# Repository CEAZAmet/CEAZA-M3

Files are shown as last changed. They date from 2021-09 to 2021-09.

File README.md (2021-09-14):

# Welcome to CEAZA-M3!
Solar charger for 12V SLA battery in CEAZA MEGA system.
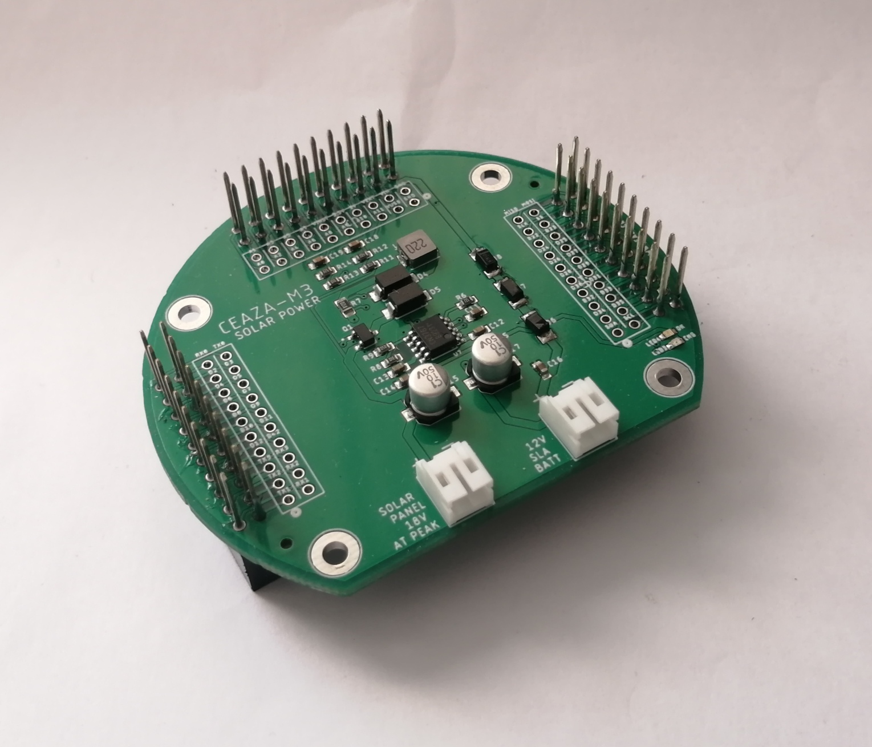
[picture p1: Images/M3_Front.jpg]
CEAZA M3 Board


# What is the CEAZA-M3?
Is a solar PWM charger for 12V SLA battery board compatible with CEAZA MEGA system, which allow recharge the system battery every day and avoid system failure due lack of energy storage.
The CEAZA M3 have below specs:
- Only for 12V SLA batteries.
- 18Vmpp Solar pannel (absolute maximum 28V)
- Solar pannel voltage monitor.
- Battery voltage monitor.
- Status LED red and green powered from solar panel which indicates charging or done respectively.
- Ready to solder pins for easy prototyping.

This board is pin compatible and should be connected to the CEAZA MEGA system to proper work.

## Documentation
A comprehensive documentation for well undertand, use or modify the CEAZA M3 board is available in our Wiki. In adition, we share with you the schematics diagrams, adns Arduino example codes.

## Quickstart guide
Install the M3 board in the CEAZA MEGA's bottom, make certain connection throuhg the boards by three 2 x 10 pin header terminals is rigth. Plug the battery and solar panel cables in the respective board terminal. be careful to avoid swap both plugs, due they are the same type of terminals. Connect the CEAZA MEGA main board system to the host PC by mini-USB connector, open the Arduino ide software, select the Arduino Mega board and the correspondign COM port.
Open any of examples scketches and upload to the board.
### WARNING!
Do not connect the battery in the main CEAZA MEGA power plug when you connect the M3 board. This may cause an electric problem in the system.

# Contact and support
For all kinds of inquiries, please contact me to my e-mail address: adrian.gallardo@ceaza.cl

# Contributing
You are welcome to contribute to the development or improvement of M3 hardware design or example application codes. Feel free to submit a new pull request via github.

# Academic Context

# Licensing

# Disclaimer
Use M3 board and examples code at your own risk. We do not encourage any malicious use of our board.

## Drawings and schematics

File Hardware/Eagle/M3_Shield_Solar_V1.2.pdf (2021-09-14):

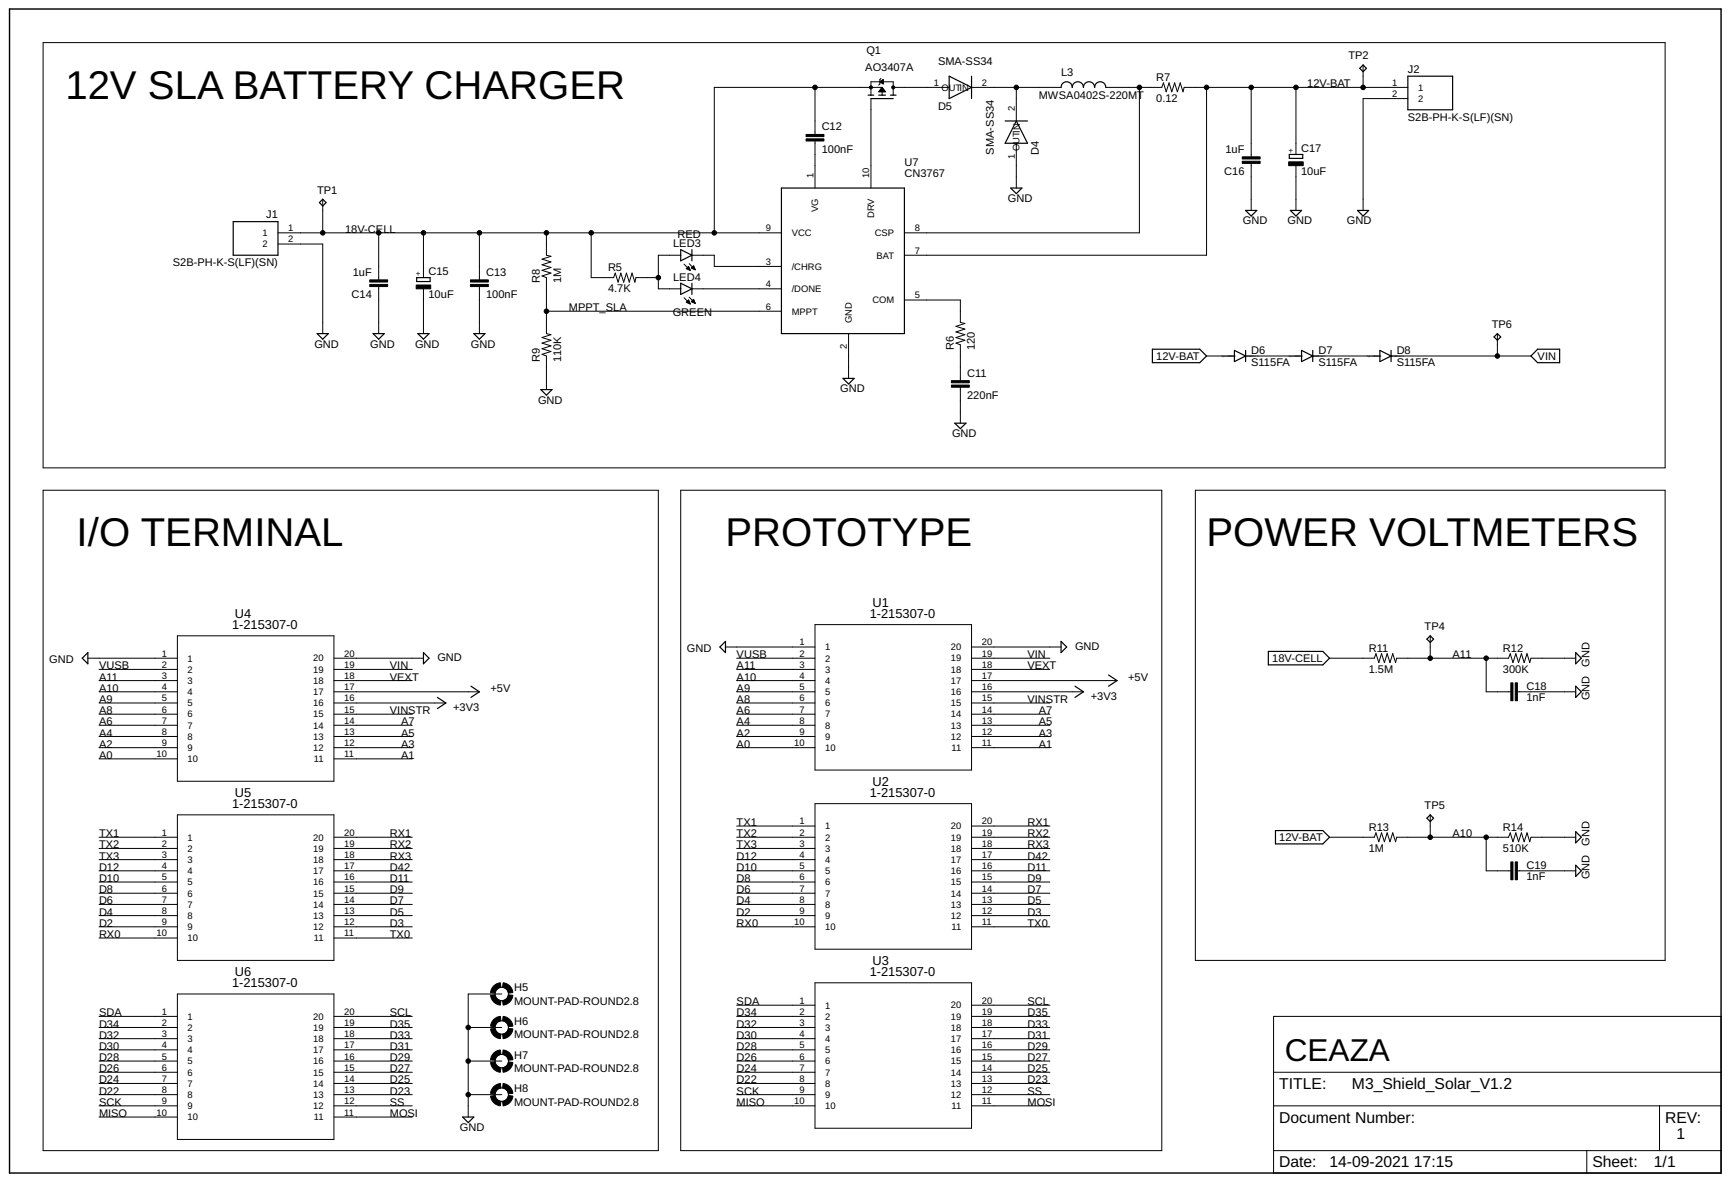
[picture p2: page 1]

+ Date: Sheet: REV: TITLE: Document Number: 14-09-2021 17:15 1/1
10uF GND

MOUNT-PAD-ROUND2.8 MOUNT-PAD-ROUND2.8 MOUNT-PAD-ROUND2.8 MOUNT-PAD-ROUND2.8 GND

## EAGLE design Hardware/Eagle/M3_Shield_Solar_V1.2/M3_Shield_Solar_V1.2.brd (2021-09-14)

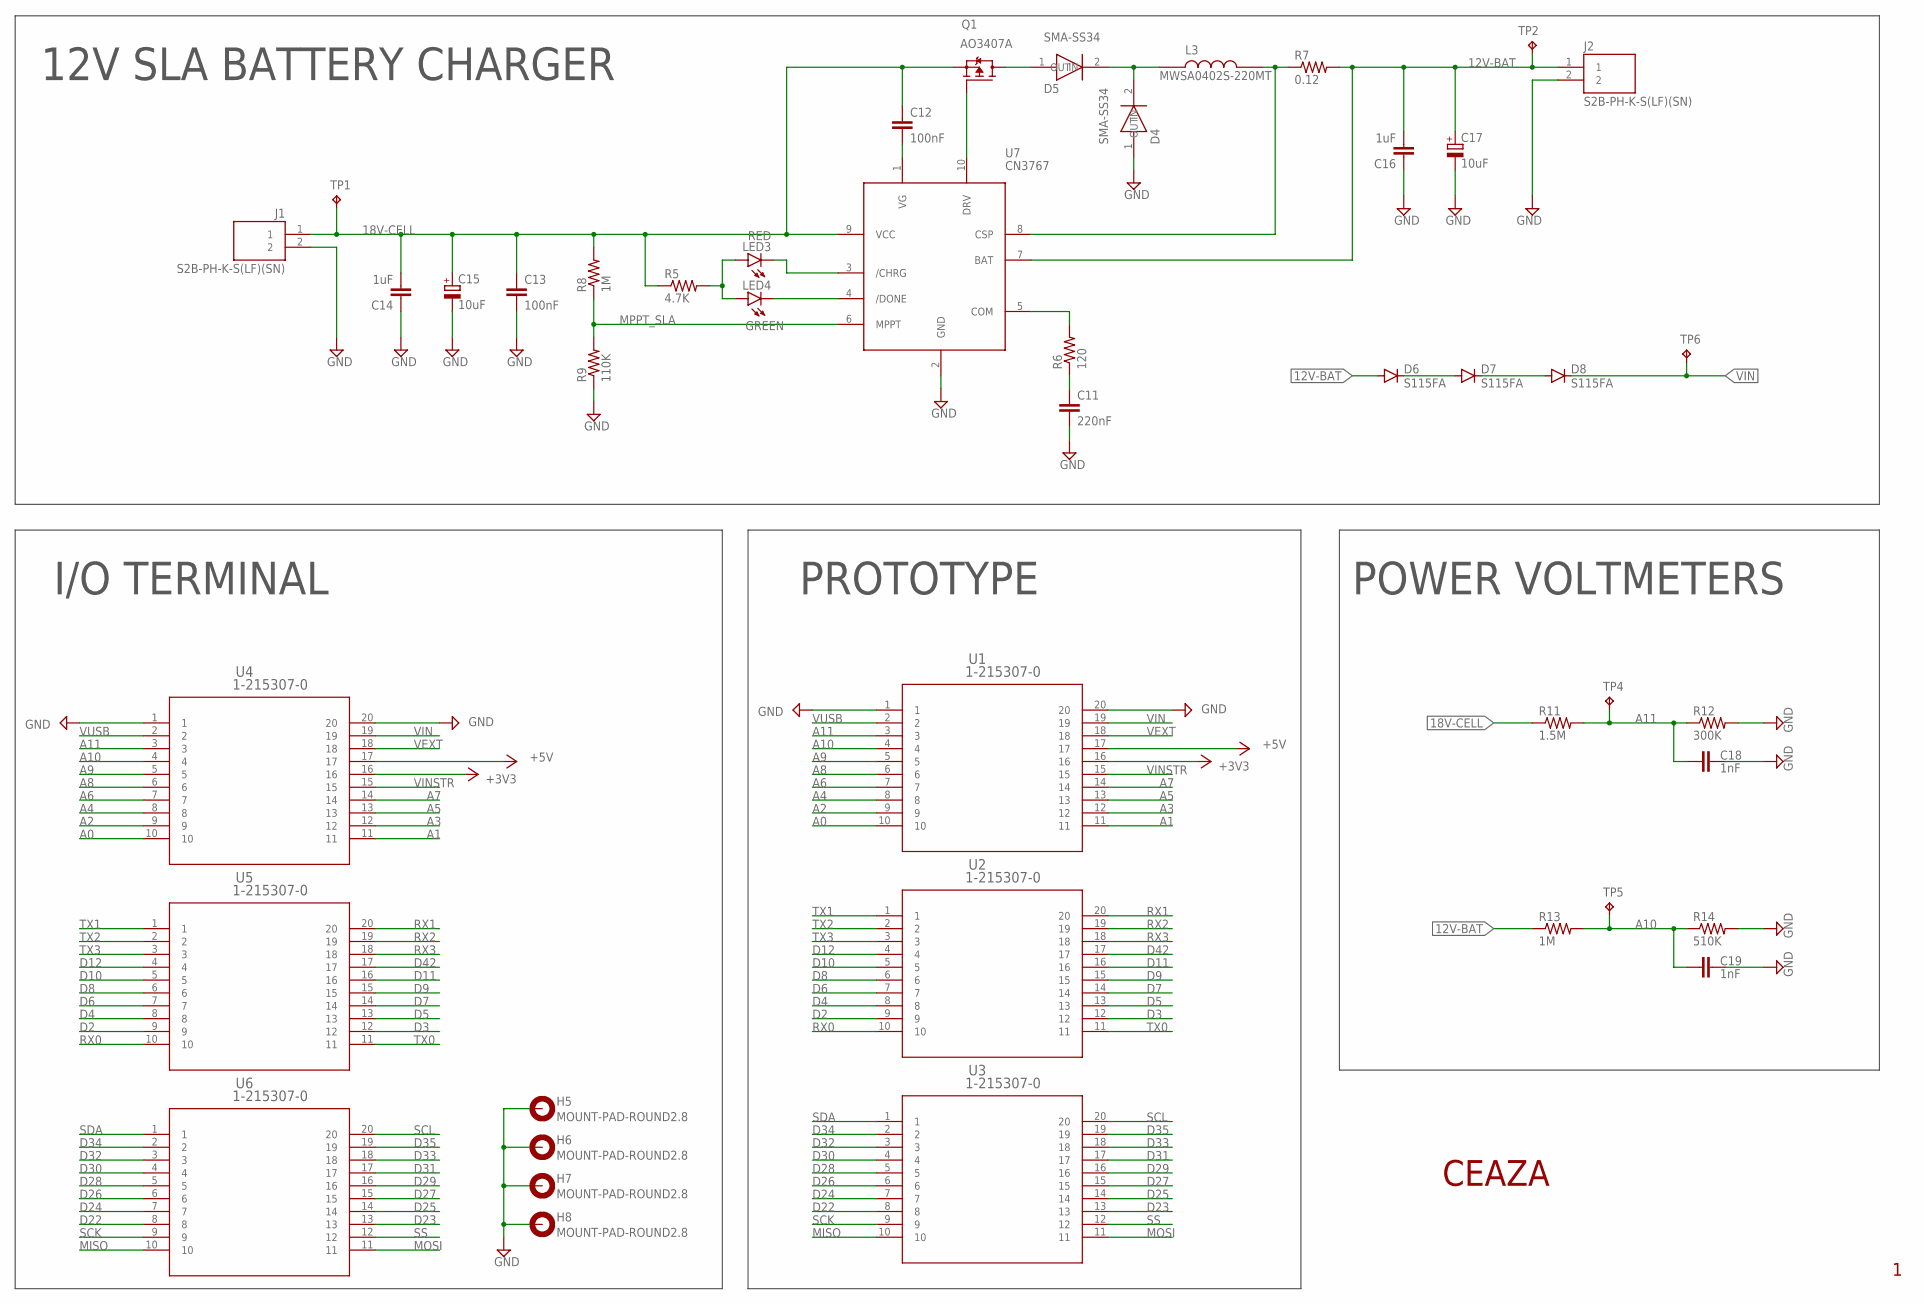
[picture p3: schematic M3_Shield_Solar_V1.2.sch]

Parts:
C11: 220nF; C0603K
C12, C13: 100nF; C0603K
C14, C16: 1uF; C0603K
C15, C17: 10uF; 153CLV-0505
C18, C19: 1nF; C0603K
D4, D5: SMA-SS34
D6, D7, D8: S115FA; SOD-123_MINI-SMA
H5, H6, H7, H8: MOUNT-PAD-ROUND2.8; 2,8-PAD
J1, J2: S2B-PH-K-S(LF)(SN); JST_S2B-PH-K-S(LF)(SN)
L3: MWSA0402S-220MT
LED3: RED; CHIPLED_0603
LED4: GREEN; CHIPLED_0603
Q1: AO3407A; SOT95P280X125-3N
R5: 4.7K; R0603
R6: 120; R0603
R7: 0.12; R0805
R8, R13: 1M; R0603
R9: 110K; R0603
R11: 1.5M; R0603
R12: 300K; R0603
R14: 510K; R0603
TP1, TP2, TP4, TP5, TP6: TPB1,27; B1,27
U1, U2, U3, U4, U5, U6: 1-215307-0
U7: CN3767

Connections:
12V-BAT: C16.2, C17.+, D6.A, J2.1, R7.2, R13.1, TP2.TP, U7.7 (BAT)
18V-CELL: C12.1, C13.1, C14.2, C15.+, J1.1, Q1.2 (S), R5.1, R8.2, R11.1, TP1.TP, U7.9 (VCC)
+3V3: U1.16, U4.16
+5V: U1.17, U4.17
A0: U1.10, U4.10
A1: U1.11, U4.11
A2: U1.9, U4.9
A3: U1.12, U4.12
A4: U1.8, U4.8
A5: U1.13, U4.13
A6: U1.7, U4.7
A7: U1.14, U4.14
A8: U1.6, U4.6
A9: U1.5, U4.5
A10: C19.1, R13.2, R14.1, TP5.TP, U1.4, U4.4
A11: C18.1, R11.2, R12.1, TP4.TP, U1.3, U4.3
D2: U2.9, U5.9
D3: U2.12, U5.12
D4: U2.8, U5.8
D5: U2.13, U5.13
D6: U2.7, U5.7
D7: U2.14, U5.14
D8: U2.6, U5.6
D9: U2.15, U5.15
D10: U2.5, U5.5
D11: U2.16, U5.16
D12: U2.4, U5.4
D22: U3.8, U6.8
D23: U3.13, U6.13
D24: U3.7, U6.7
D25: U3.14, U6.14
D26: U3.6, U6.6
D27: U3.15, U6.15
D28: U3.5, U6.5
D29: U3.16, U6.16
D30: U3.4, U6.4
D31: U3.17, U6.17
D32: U3.3, U6.3
D33: U3.18, U6.18
D34: U3.2, U6.2
D35: U3.19, U6.19
D42: U2.17, U5.17
GND: C11.2, C13.2, C14.1, C15.-, C16.1, C17.-, C18.2, C19.2, D4.1 (IN), H5.B2,8, H6.B2,8, H7.B2,8, H8.B2,8, J1.2, J2.2, R9.1, R12.2, R14.2, U1.1, U1.20, U4.1, U4.20, U7.2 (GND)
MISO: U3.10, U6.10
MOSI: U3.11, U6.11
MPPT_SLA: R8.1, R9.2, U7.6 (MPPT)
unnamed: LED4.C, U7.4 (/DONE)
unnamed: LED3.C, U7.3 (/CHRG)
unnamed: LED3.A, LED4.A, R5.2
unnamed: R6.2, U7.5 (COM)
unnamed: C11.1, R6.1
unnamed: D6.C, D7.A
unnamed: D7.C, D8.A
unnamed: L3.P$2, R7.1, U7.8 (CSP)
unnamed: D4.2 (OUT), D5.2 (OUT), L3.P$1
unnamed: C12.2, U7.1 (VG)
unnamed: Q1.1 (G), U7.10 (DRV)
unnamed: D5.1 (IN), Q1.3 (D)
RX0: U2.10, U5.10
RX1: U2.20, U5.20
RX2: U2.19, U5.19
RX3: U2.18, U5.18
SCK: U3.9, U6.9
SCL: U3.20, U6.20
SDA: U3.1, U6.1
SS: U3.12, U6.12
TX0: U2.11, U5.11
TX1: U2.1, U5.1
TX2: U2.2, U5.2
TX3: U2.3, U5.3
VEXT: U1.18, U4.18
VIN: D8.C, TP6.TP, U1.19, U4.19
VINSTR: U1.15, U4.15
VUSB: U1.2, U4.2

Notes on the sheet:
12V SLA BATTERY CHARGER
POWER VOLTMETERS
I/O TERMINAL
PROTOTYPE
CEAZA

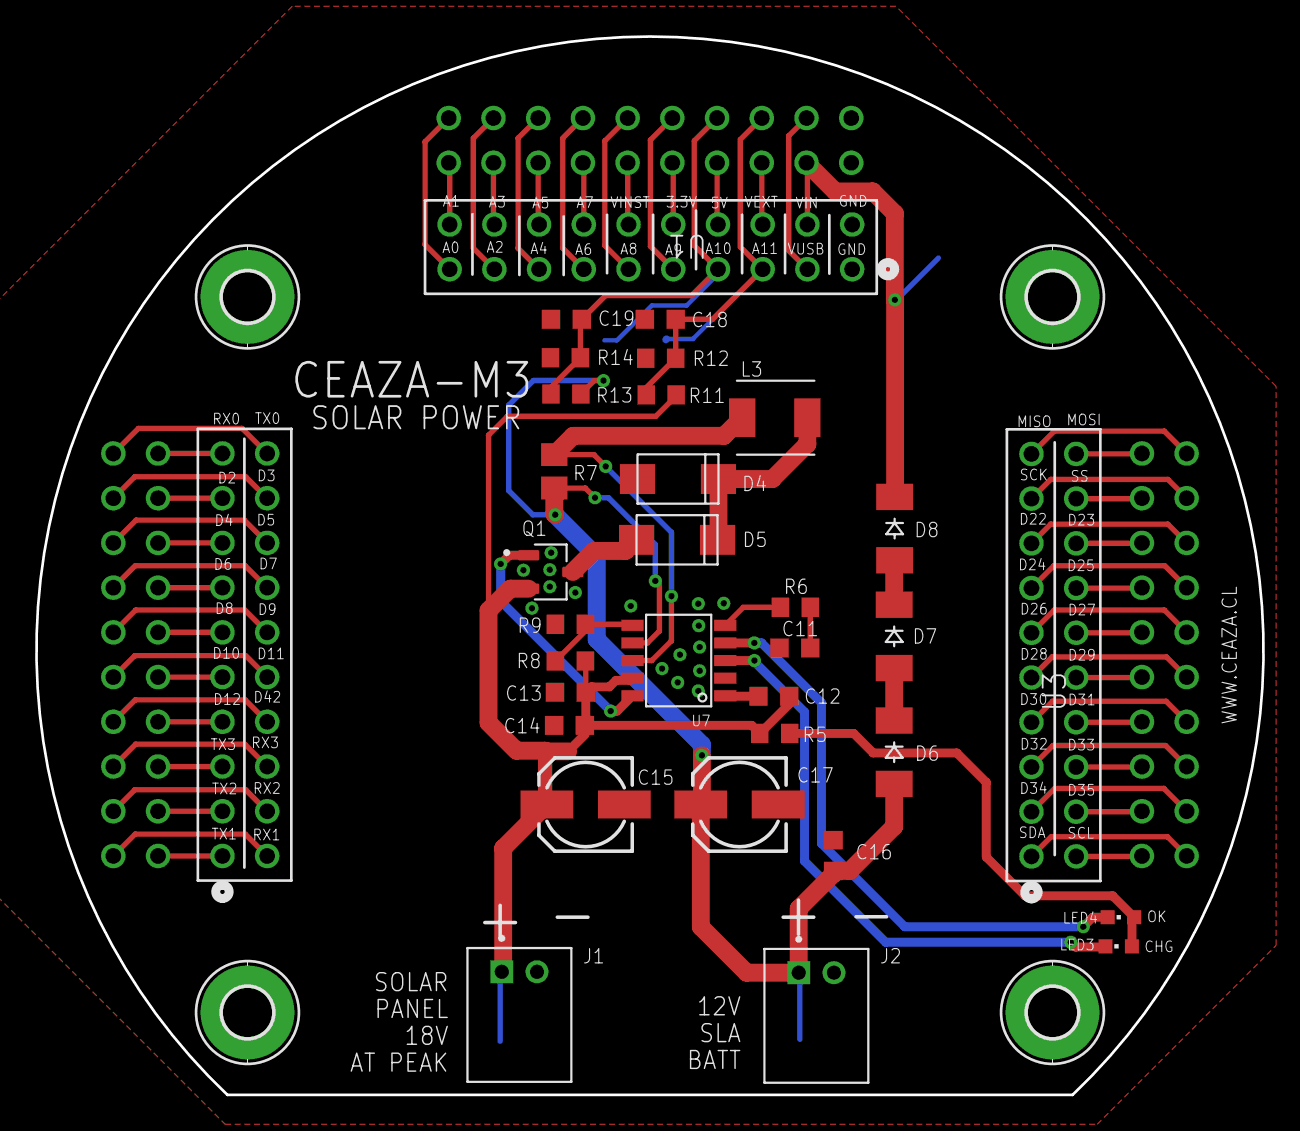
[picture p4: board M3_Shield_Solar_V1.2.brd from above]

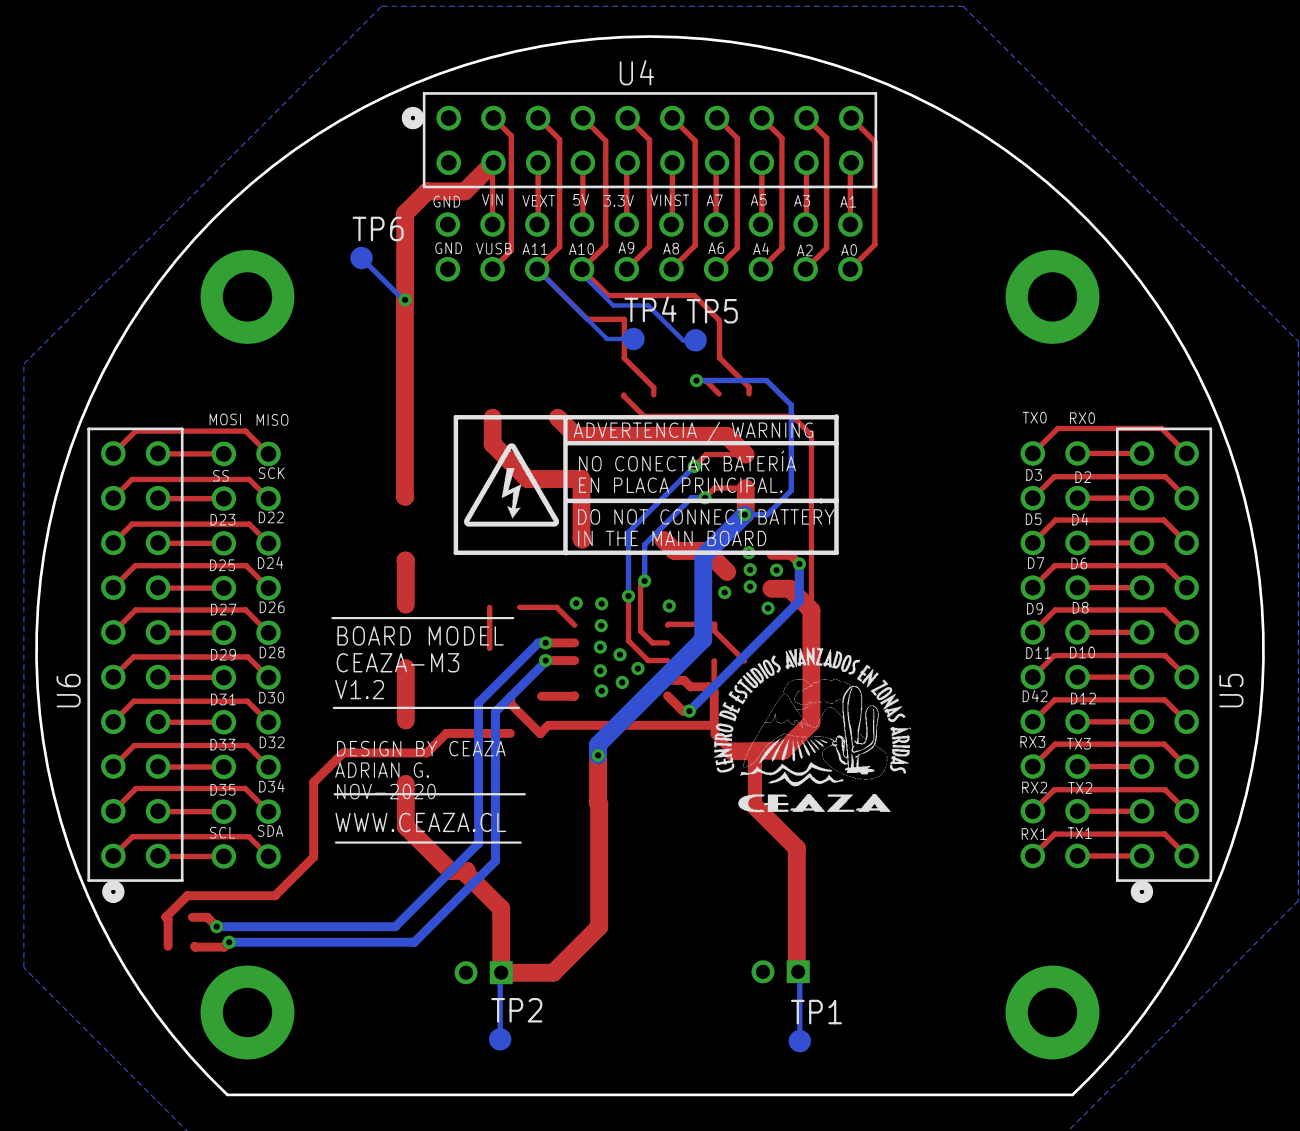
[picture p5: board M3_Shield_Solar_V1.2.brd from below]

Board: 2 copper layers, 69.7 x 60.1 mm, 45 parts (8 on the bottom side), 74 nets.

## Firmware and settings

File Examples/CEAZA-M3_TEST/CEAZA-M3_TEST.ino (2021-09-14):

/*
 * For this code you have to connect an M3 board to a CEAZA MEGA borad.
 * To program the CEAZA MEGA borad you have to select the "Arduino Mega or Mega 2560" board.
 * 
 * This code show by serial monitor the battery voltage and solar panel voltage read from M3 board.
 * Make sure the rigth plug in of battery and solar panel in M3 board.
 * 
 * WARNING!:
 * Do not connect the battery in the main CEAZA MEGA board power plug when the M3 board is in use.
 * 
 *  https://github.com/adgallardo/CEAZA-M3
 */
#define SOLAR_PANEL_MONITOR_PIN A11   // Analog port for solar monitor
#define BATTERY_MONITOR_PIN     A10   // Analog port for battery monitor

void setup() {
  Serial.begin(115200);
  Serial.println("CEAZA-M3 Board Test!");
}

void loop() {
  float vbat = analogRead(BATTERY_MONITOR_PIN)/69.1;      // Calculated battery voltage
  float vsun = analogRead(SOLAR_PANEL_MONITOR_PIN)/34.1;  // Calculated solar panel voltage

  Serial.print("- Battery Voltage:     ");Serial.print(vbat);Serial.println("V");
  Serial.print("- Solar Panel Voltage: ");Serial.print(vsun);Serial.println("V\n");

  delay(5000);
}
